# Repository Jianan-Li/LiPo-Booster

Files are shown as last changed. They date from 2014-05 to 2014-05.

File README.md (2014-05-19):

LiPo-Booster
============
A breadboard-friendly boost converter board based on TPS61230 from Texus Instrument. The input voltage from a single cell LiPo battery is converted to 5V for use with 5V systems.

v1: Minimum component count

v2: Configurable UVLO using three additional resistors

Please refer to the TPS61230 datasheet for UVLO resistors calculation.

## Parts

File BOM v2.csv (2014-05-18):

Name | Vendor | Part Number | Quantity
TPS61230 Boost Converter | Digikey | TPS61230DRCR | 1
1uH Inductor | Coilcraft | XFL4020-102MEB | 1
10nF Capacitor | Digikey | C0603C103J5RACTU | 1
22uF Capacitor | Digikey | C1608X5R1A226M080AC | 3
1k Resistor | Digikey | ERJ-3GEYJ102V | 1
100k Resistor | Digikey | RHM100KCFCT-ND | 1
402k Resistor | Digikey | RHM402KCFCT-ND | 1
Green LED | Digikey | LTST-C190KGKT | 1
SPDT Slide Switch | Digikey | JS102011SAQN | 1
JST Connector | Digikey | 455-1749-1-ND | 1
2-pin Header |  |  | 2
Configurable UVLO (Resistor values depend on the desired UVLO voltage)
The following combination gives a UVLO voltage of 3.42V (falling) and 3.57V (rising)
1M Resistor | Digikey | ERJ-3EKF1004V | 1
499k Resistor | Digikey | ERJ-3EKF4993V | 1
0 Resistor | Digikey | ERJ-3GEY0R00V | 1

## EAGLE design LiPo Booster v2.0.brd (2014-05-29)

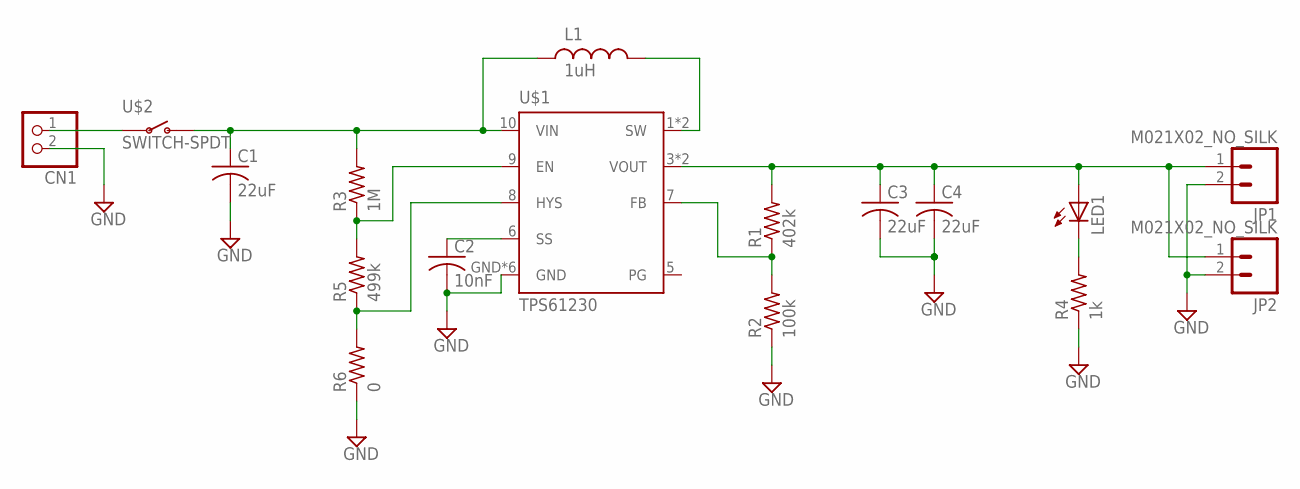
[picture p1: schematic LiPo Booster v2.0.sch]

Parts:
C1, C3, C4: 22uF; C0603K
C2: 10nF; C0603K
CN1: JST_2PIN-SMT-RA; JST-PH-2-SMT-RA
JP1, JP2: M021X02_NO_SILK; 1X02_NO_SILK
L1: 1uH; XFL4020
LED1: LEDCHIPLED_0603; CHIPLED_0603
R1: 402k; R0603
R2: 100k; R0603
R3: 1M; R0603
R4: 1k; R0603
R5: 499k; R0603
R6: 0; R0603
U$1: TPS61230; DRC-S-PVSON-N11
U$2: SWITCH-SPDT; JS102011

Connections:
GND: C1.2, C2.2, C3.2, C4.2, CN1.2 (1), JP1.2, JP2.2, R2.1, R4.1, R6.1, U$1.GND, U$1.GND@1 (GND), U$1.GND@2 (GND), U$1.GND@3 (GND), U$1.GND@4 (GND), U$1.GND@5 (GND)
IND: L1.P$2 (2), U$1.1 (SW), U$1.2 (SW)
unnamed: R3.1, R5.2, U$1.9 (EN)
unnamed: LED1.C, R4.2
unnamed: C2.1, U$1.6 (SS)
unnamed: R5.1, R6.2, U$1.8 (HYS)
unnamed: R1.1, R2.2, U$1.7 (FB)
PG: U$1.5 (PG)
VBATT: CN1.1 (2), U$2.P$3
VIN: C1.1, L1.P$1 (1), R3.2, U$1.10 (VIN), U$2.P$2 (O)
VOUT: C3.1, C4.1, JP1.1, JP2.1, LED1.A, R1.2, U$1.3 (VOUT), U$1.4 (VOUT)

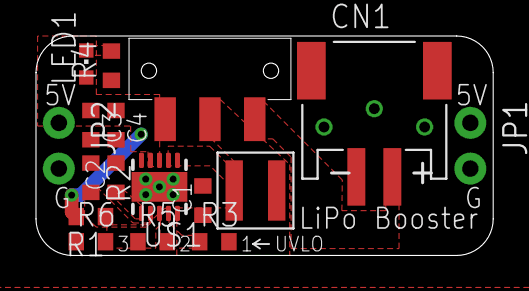
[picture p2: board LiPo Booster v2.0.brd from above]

Board: 2 copper layers, 25.4 x 12.2 mm, 18 parts (0 on the bottom side), 10 nets.

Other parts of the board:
U$3: ARROW<--

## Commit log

2014-05-15 Lipo Booster v1
    Lipo Booster v1 based on TPS61230
    [Lipo Booster v1.brd, Lipo Booster v1.sch]
2014-05-15 Rename Lipo Booster v1.brd to LiPo Booster v1.brd
    [LiPo Booster v1.brd]
2014-05-15 Rename Lipo Booster v1.sch to LiPo Booster v1.sch
    [LiPo Booster v1.sch]
2014-05-16 BOM v1.1
    [BOM.csv, BOM.xlsx]
2014-05-16 Update BOM v1.1.csv
    [BOM v1.1.csv]
2014-05-18 v2 with configurable UVLO
    [BOM v2.csv, LiPo Booster v2.0.brd, LiPo Booster v2.0.sch]
2014-05-18 Minor adjustments of component placement
    [LiPo Booster v1.2.brd, LiPo Booster v1.2.sch]
2014-05-18 Update BOM v2.csv
    [BOM v2.csv]

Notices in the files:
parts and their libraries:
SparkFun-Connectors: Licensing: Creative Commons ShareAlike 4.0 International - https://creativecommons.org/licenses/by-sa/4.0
